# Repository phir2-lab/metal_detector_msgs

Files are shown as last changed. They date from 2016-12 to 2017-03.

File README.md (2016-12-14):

# Open Hardware, ROS-enable metal detector

This is a ROS package for the metal detector used in the [HRATC2017](http://inf.ufrgs.br/hratc2017/HRATC2017/Welcome.html) robot programming competition. The detector is based on open-hardware and software design.

## Usage

Program your Arduino with the firmware located in the "electronics/arduino_firmware" folder, connect it to your computer and run the launch file "detector.launch" with:

```
roslaunch metal_detector_msgs detector.launch
```

Or run the "arduino_node.py" node with:

```
rosrun metal_detector_msgs arduino_node.py [args]
```

The arguments (optional) to be passed to the node are:
* -b, --baud : Serial BAUD rate of the Arduino (default is 9600)
* --vid 	 : Vendor ID of the Arduino (default is 2341 for Arduino UNO)

This can also be seen when passing "-h" as argument for the node.

## Dependencies
* [ROS Indigo](http://wiki.ros.org/indigo)
* [pySerial](http://pyserial.readthedocs.io/en/latest/pyserial.html)

## Installation

Clone this package to your [Catkin Workspace](http://wiki.ros.org/catkin/Tutorials/create_a_workspace) "src" folder and [build your catkin packages](http://wiki.ros.org/catkin/Tutorials/using_a_workspace).

## Topic

The node receives frequency measurements from an Arduino via Serial Communication and publishes a topic of the Coil message type, of which the definition can be seen in the "msg" folder. Please see the readme of the "msg" folder for more information regarding interface with the coils.

## Parameters

The package uses ROS' parameter server to get and set its calibration parameters. They are defined as:

* calibration/sat : Saturation value for the coils in Hz
* calibration/ref : The desired reference value (when coils saturate)

By default, these parameters are set to "1.0".
The node also caps the readings to the reference value. In other words, it returns readings in the range of [0 - ref].

The parameters can be set statically via the "detector.launch" file. Just change the <param> tags accordingly, as seen in the example below:

```
<param name="calibration/sat" type="double" value="1853" /> 
```

Alternatively, to set the parameters dynamically, use the command below after launching the detector node:

```
rosparam set calibration/sat 1853
```

To check the value of a parameter, use the "rosparam get" command:
```
rosparam get calibration/sat
```

## Package organization

- model: has the Solidworks and Gazebo models for the metal detector;
- eletronics: it has the hardware design, eletronics, and Arduino programming;
- other dirs: ROS-related files such as launch, node, msg, etc.

## Troubleshooting

* Can't connect to my Arduino

The "arduino_node.py" sweeps your /dev/ folder for all available serial connections and finds the Arduino automatically via its Vendor ID (vid). The Arduino's vid can be set through the "--vid" argument when running the node, or by changing the "args" parameter in the launch file. To find out what your Arduino vid is, connect it to a computer and run the "lsusb" command in a terminal. The vid will be there, like this:

<pre>
Bus 002 Device 006: ID 0cf3:e005 Atheros Communications, Inc. 
Bus 002 Device 003: ID 0c45:6712 Microdia 
Bus 002 Device 009: ID <b>2341</b>:0043 Arduino SA Uno R3 (CDC ACM)
                          ^
                       [This is your VID]   
</pre>

## Credits

- The original eletronics board was designed by [LucasLab](https://translate.google.com/translate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)
- The integration of the eletronics board with Arduino is by Augusto Bergamin;
- The Arduino firmware is by Augusto Bergamin and Renan Maidana;
- The ROS node design and ROS launch is by Renan Maidana;
- Conversion from SolidWorks to Gazebo by Renan Maffei and Mathias Mantelli.
- Readmes edits by Alexandre Amory.

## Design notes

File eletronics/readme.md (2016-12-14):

# Electronics

This directory you will find:

- Arduino Firmware
- original metal detector PCB design [LucasLab](https://translate.google.com/translate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)
- modified metal detector PCB design by Augusto Bergamin
  - integrated with Arduino UNO
  - including support to two coils

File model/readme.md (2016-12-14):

# Metal Detector Support

This model, drawn in SolidWorks and exported to Gazebo, is the support/arm for the metal detector.

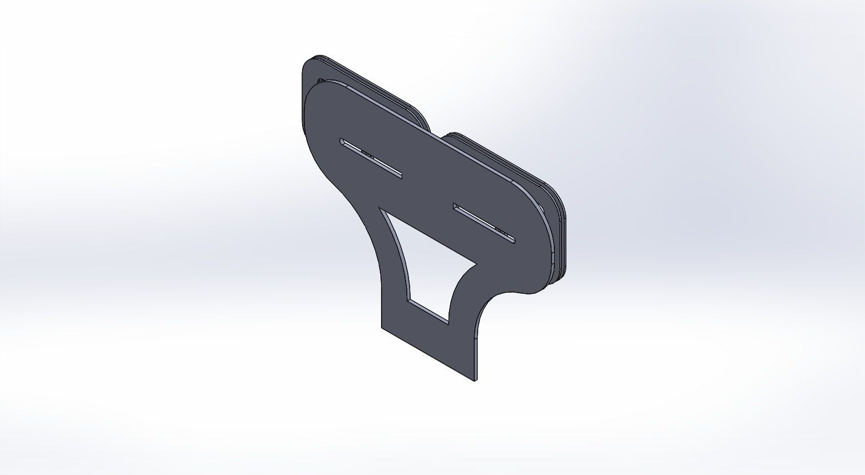
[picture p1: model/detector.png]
Metal detector arm


This image shows the position of the coils.

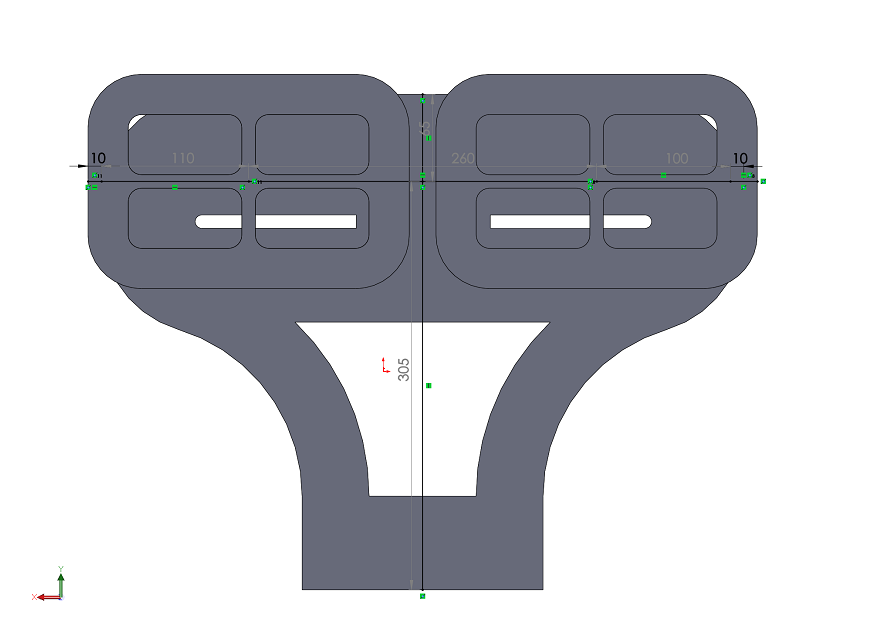
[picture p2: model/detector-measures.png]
Metal detector arm


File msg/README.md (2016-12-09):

### Note

In the topic published by the metal detector node, the coils' measurements are contained in the "left_coil" and "right_coil" for the left and right coils respectively, in the Coil message type (Coil.msg). The coils are measured one at a time, and switching between them occurs in a fixed interval.

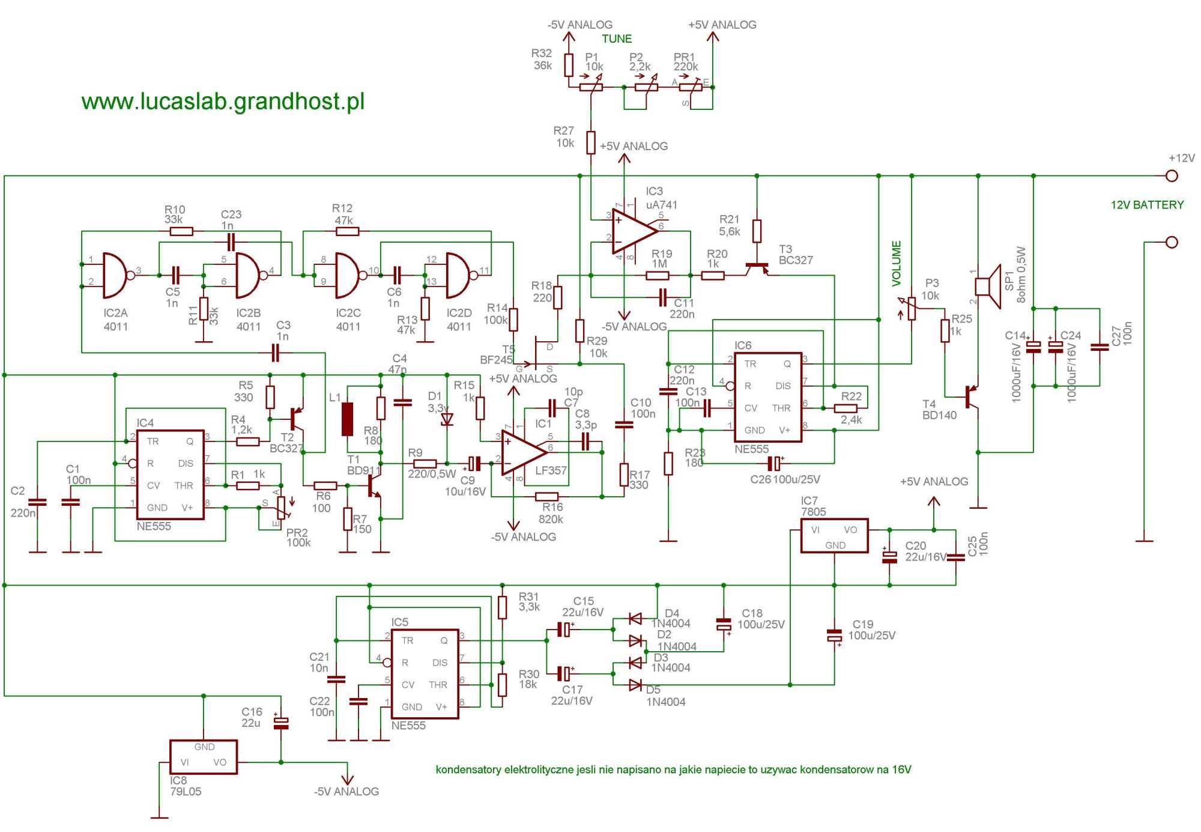
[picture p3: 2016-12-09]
eletronics/pcb/schematwykrywacza.JPG

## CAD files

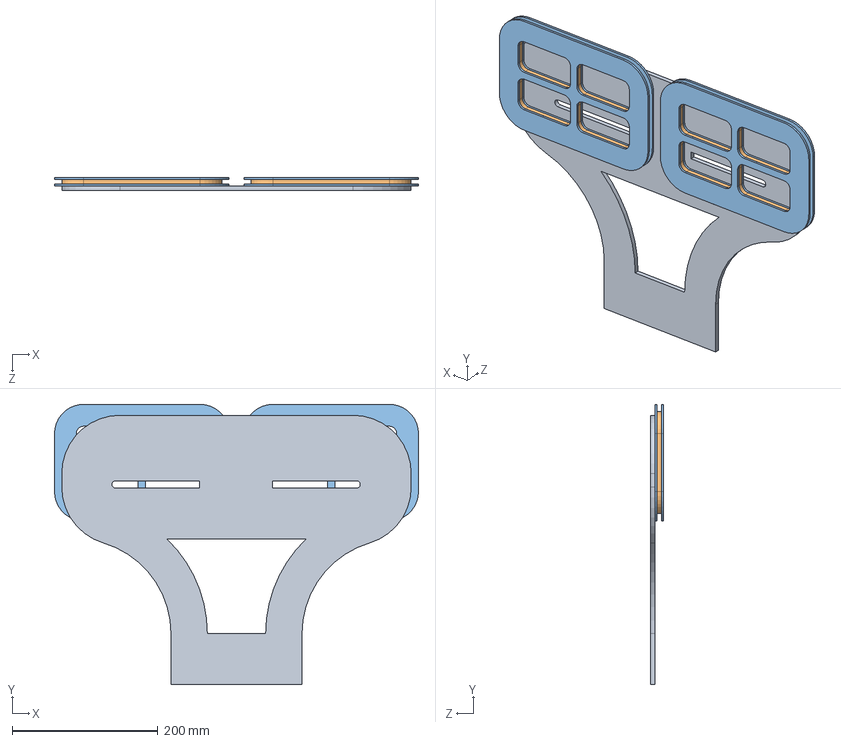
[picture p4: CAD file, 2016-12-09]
model/solidworks/Detector.SLDASM
500.0 x 385.0 x 18.0 mm
Suportev5
Bobina x 2
BobinaBorda x 4

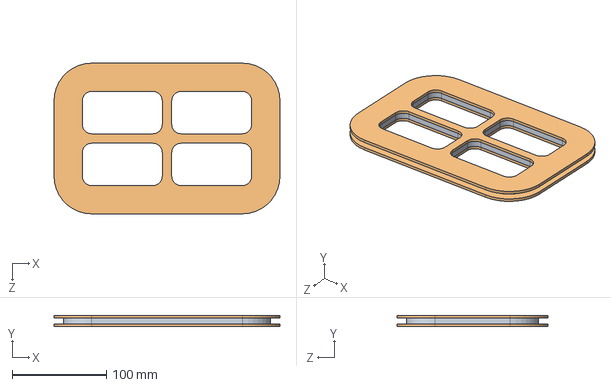
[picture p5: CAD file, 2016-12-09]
model/solidworks/MontagemBobina.SLDASM
240.0 x 12.0 x 160.0 mm
Bobina
BobinaBorda x 2

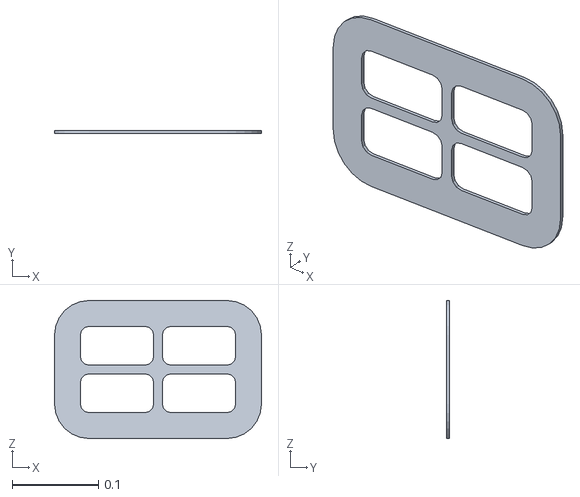
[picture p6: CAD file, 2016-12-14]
model/gazebo/meshes/left_coil.STL
0.24 x 0.003 x 0.16

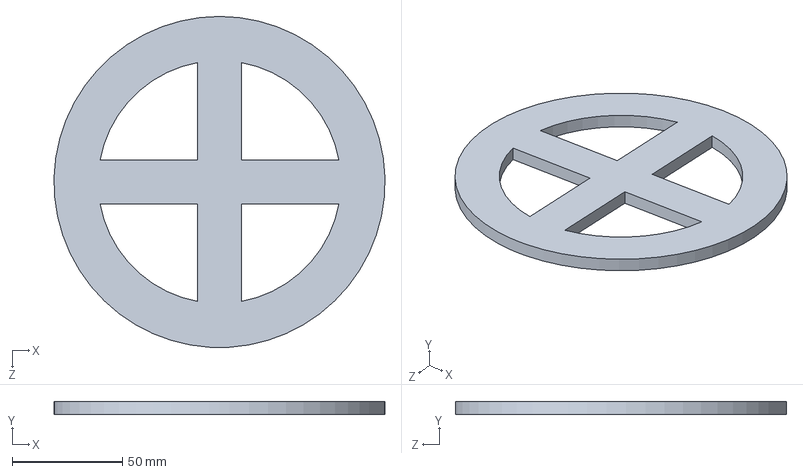
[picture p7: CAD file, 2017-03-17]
model/solidworks/Bobina lateral.SLDPRT
149.9 x 6.00 x 150.0 mm

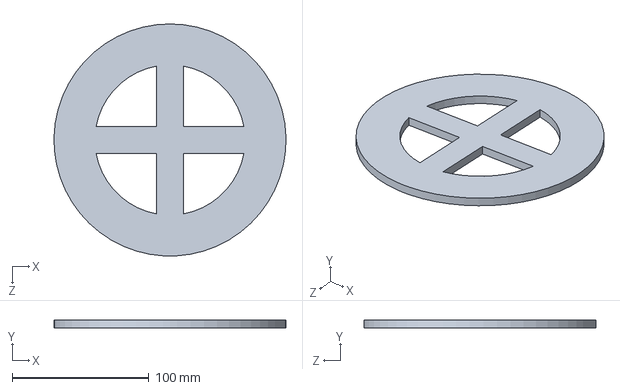
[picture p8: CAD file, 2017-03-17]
model/solidworks/Bobina TOP.SLDPRT
169.9 x 6.00 x 170.0 mm

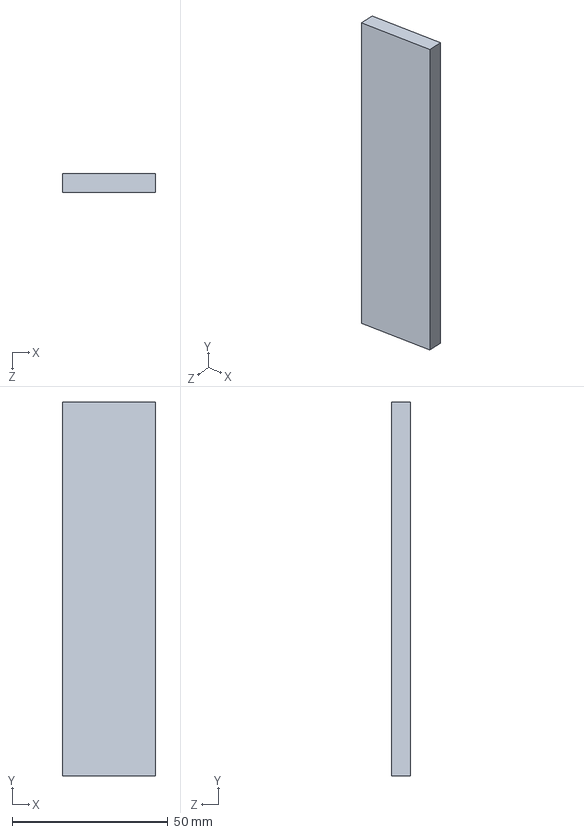
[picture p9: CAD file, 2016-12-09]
model/solidworks/Suporte-Dobradica.SLDPRT
30.0 x 120.0 x 6.00 mm

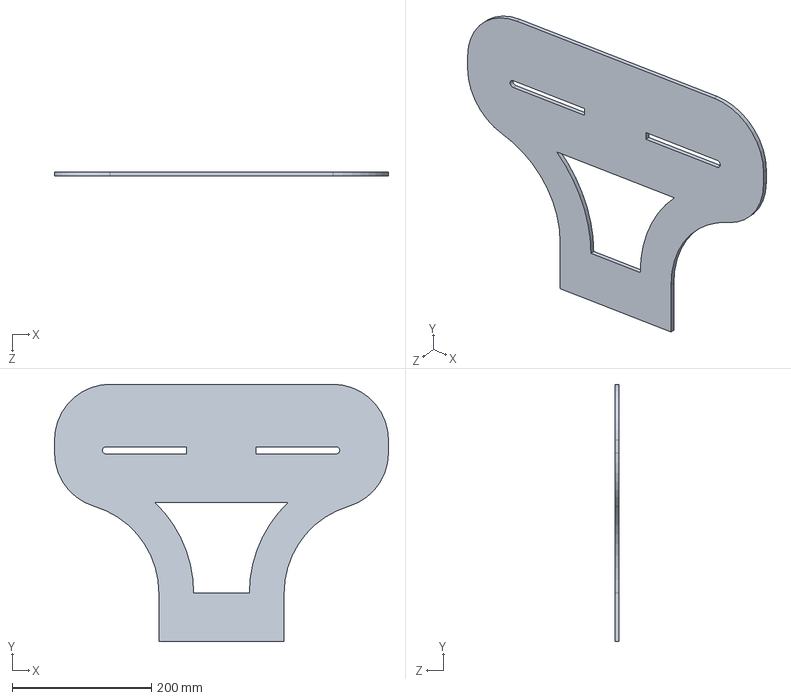
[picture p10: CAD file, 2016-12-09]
model/solidworks/Suportev5.SLDPRT
480.0 x 370.0 x 6.00 mm

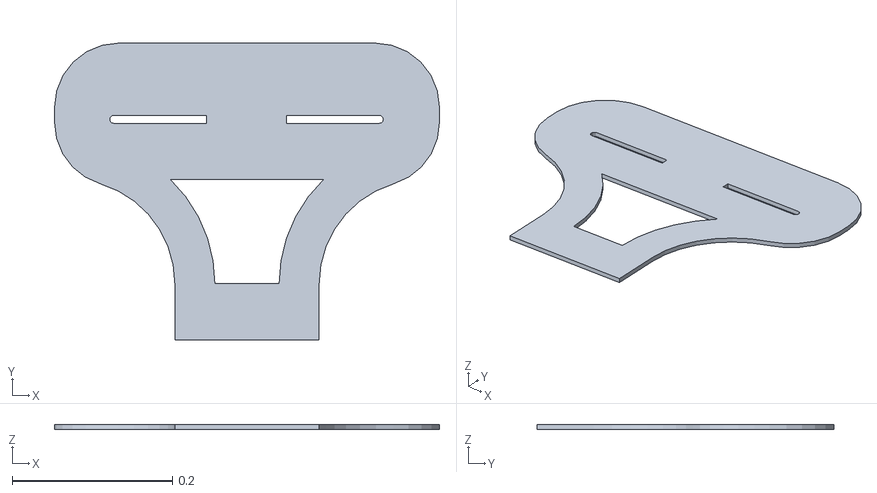
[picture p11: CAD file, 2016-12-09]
model/gazebo/meshes/metal_detector_support.STL
0.48 x 0.37 x 0.006

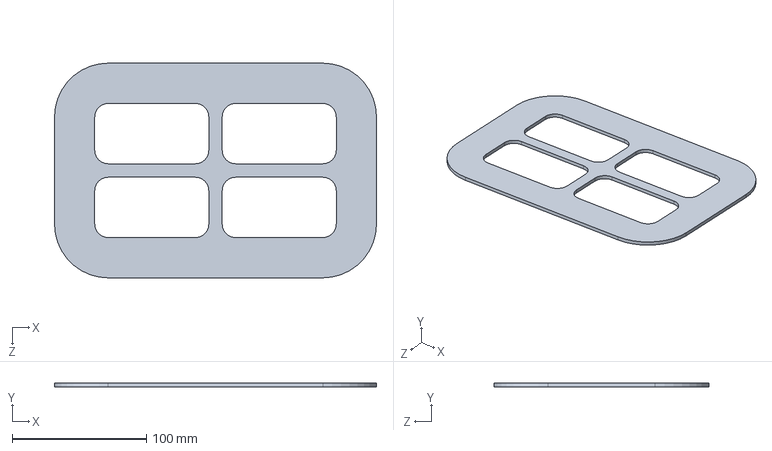
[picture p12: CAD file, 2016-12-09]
model/solidworks/BobinaBorda.SLDPRT
240.0 x 3.00 x 160.0 mm

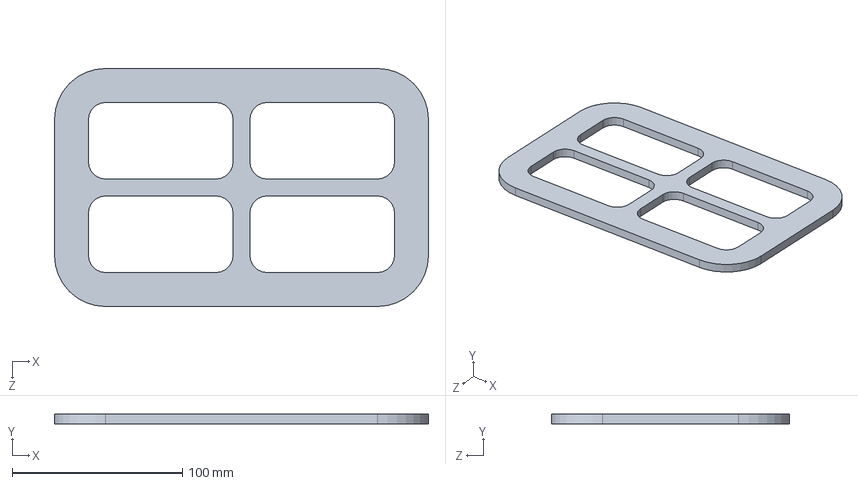
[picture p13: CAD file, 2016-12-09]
model/solidworks/Bobina.SLDPRT
220.0 x 6.00 x 140.0 mm

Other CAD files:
model/gazebo/meshes/right_coil_support.STL
model/gazebo/meshes/left_coil_support.STL
model/gazebo/meshes/right_coil.STL

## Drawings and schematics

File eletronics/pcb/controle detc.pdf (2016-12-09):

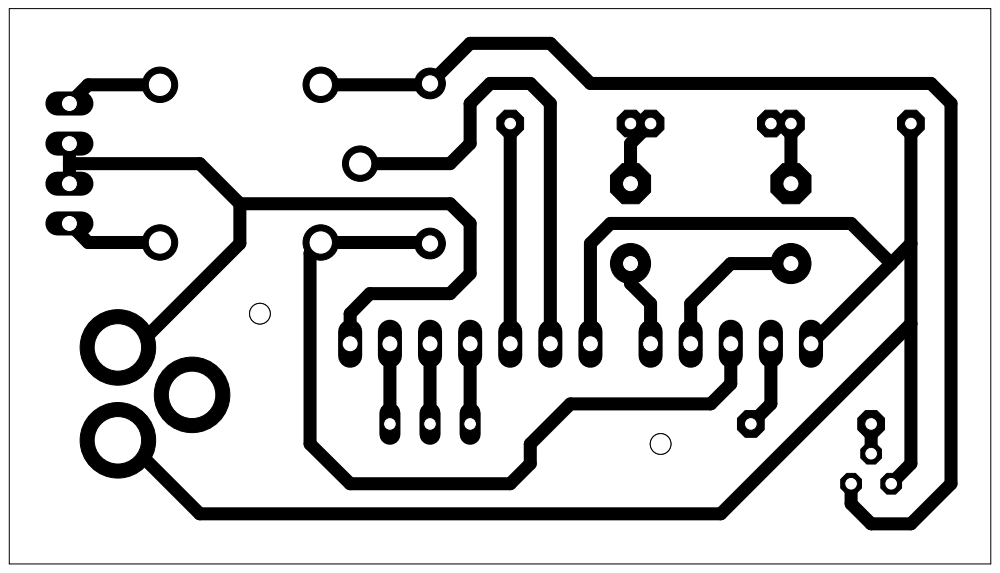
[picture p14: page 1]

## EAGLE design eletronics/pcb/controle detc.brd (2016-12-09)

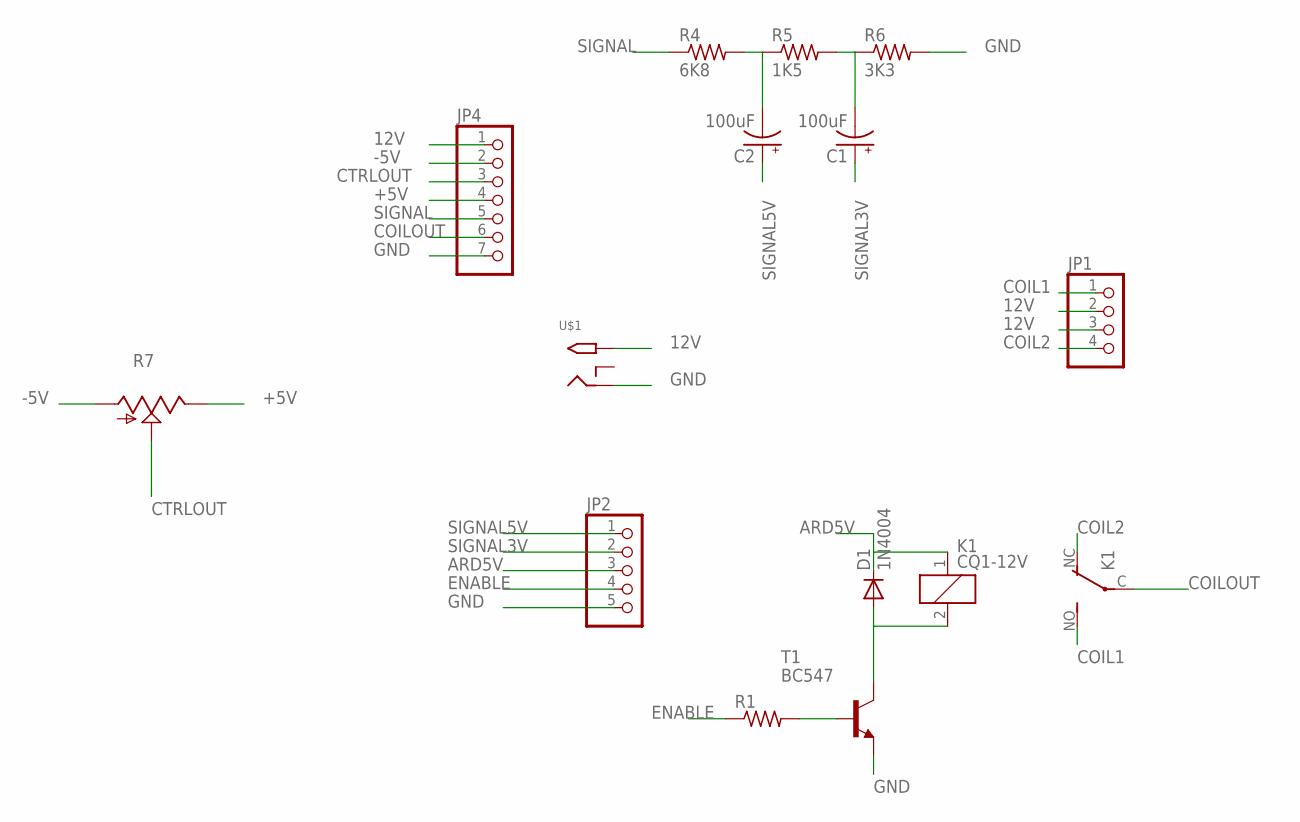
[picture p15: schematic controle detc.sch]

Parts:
C1, C2: 100uF; E5-8,5
D1: 1N4004; DO41-10
JP1: PINHD-1X4; 1X04
JP2: PINHD-1X5; 1X05
JP4: PINHD-1X7; 1X07
K1: CQ1-12V; CQ1
R1: R-US_0207/7; 0207/7
R4: 6K8; 0207/7
R5: 1K5; 0207/7
R6: 3K3; 0207/7
R7: TRIM_US-S64W; S64W
T1: BC547; TO92
U$1: 2.1MMJACKTHM; PJ-102A

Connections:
12V: JP1.2, JP1.3, JP4.1, U$1.TIP
+5V: JP4.4, R7.E
-5V: JP4.2, R7.A
ARD5V: D1.C, JP2.3, K1.1
COIL1: JP1.1, K1.NO (S)
COIL2: JP1.4, K1.NC (O)
COILOUT: JP4.6, K1.C
CTRLOUT: JP4.3, R7.S
ENABLE: JP2.4, R1.1
GND: JP2.5, JP4.7, R6.2, T1.1 (E), U$1.RING
unnamed: R1.2, T1.2 (B)
unnamed: D1.A, K1.2, T1.3 (C)
unnamed: C2.-, R4.2, R5.1
unnamed: C1.-, R5.2, R6.1
SIGNAL: JP4.5, R4.1
SIGNAL3V: C1.+, JP2.2
SIGNAL5V: C2.+, JP2.1

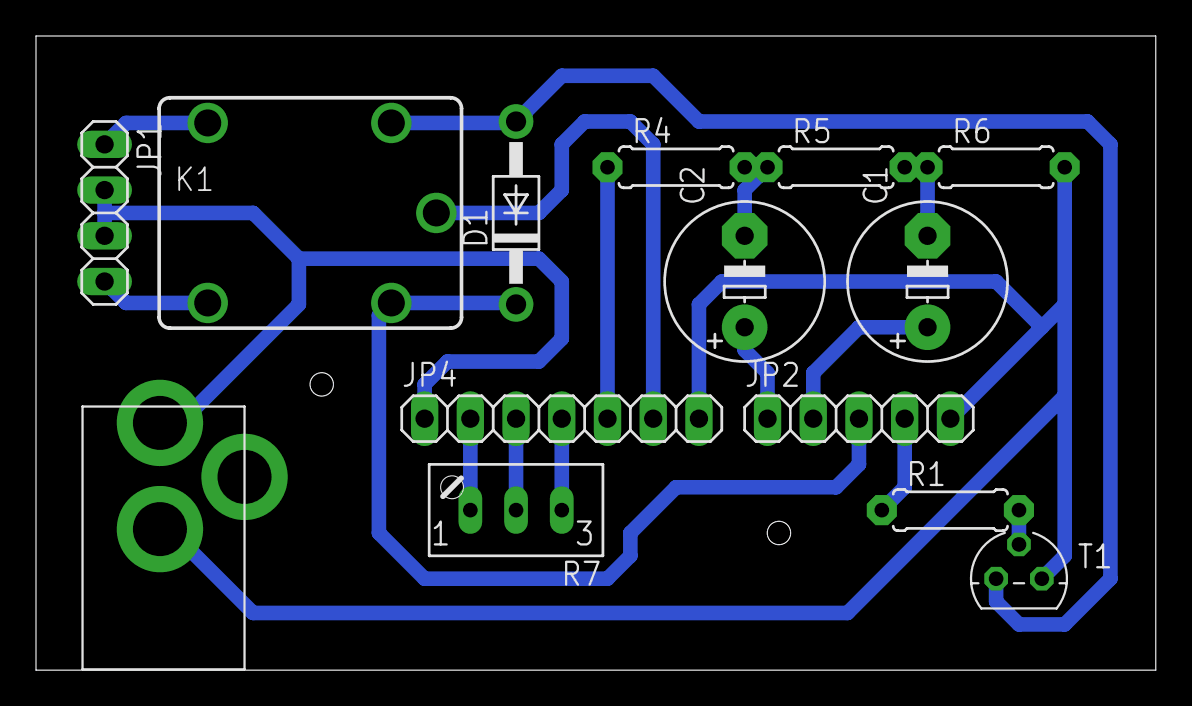
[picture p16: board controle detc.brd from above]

Board: 2 copper layers, 62.2 x 35.2 mm, 14 parts (0 on the bottom side), 17 nets.

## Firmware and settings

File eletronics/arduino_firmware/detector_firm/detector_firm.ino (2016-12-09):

#include <avr/io.h>
#include <avr/interrupt.h>

volatile double temp;
volatile int freqL = 0;
volatile int freqR = 0;
long int swit = 0;
bool Rstate = 0;

//Interrupt vector for INT0 (pin D2)
ISR (INT0_vect)
{
  if(swit >= 400)
  {
  	//Bobina direita
    if(Rstate == true){
      freqR = (1/((micros() - temp)/1000000));
  	}
  	//Bobina esquerda
    else{
      freqL = (1/((micros() - temp)/1000000));
  	}
  }
  temp = micros();
}

void setup()
{
  pinMode(13,OUTPUT);	//Relay pin (D13)
  temp = micros();

  Serial.begin(9600);
  
  cli(); //Disable interrupts for setup

  //Interrupt (on Arduino Uno pin 2)
  DDRD &= ~(1 << DDD2);     // Clear the PD2 pin
  PORTD |= (1 << PORTD2);    // turn On the Pull-up
  EICRA |= (1 << ISC01);    // set INT0 to trigger on falling edge
  EIMSK |= (1 << INT0);     // Turns on INT0
  
  sei();	//Re-enable interruptsd
}

void loop()
{
  //After some time, switch coils
  if(swit >= 800)
  { 
    Rstate = not(Rstate); 
    swit = 0;
    digitalWrite(13,Rstate);
    freqL = 0;
    freqR = 0;
  }
  
  Serial.print(freqL);
  Serial.print(",");
  Serial.print(freqR);
  Serial.print("\n");

  swit++;
}

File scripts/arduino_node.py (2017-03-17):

#!/usr/bin/env python

import os
import sys
import time
import rospy
import signal
import serial
import argparse
import serial.tools.list_ports
from serial import SerialException
from metal_detector_msgs.msg import Coil

# ROS Parameters
pub_freq = 10
pub_topic = 'metal_detector'
ser = serial.Serial()

# Coil message
coil_msg = Coil()
coil_msg.header.frame_id = 'Coils'
coil_msg.header.seq = 0

# Argument parser
parser = argparse.ArgumentParser()

# Regular arguments
parser.add_argument("-b", "--baud",
                    default=9600,
                    help='defines baud rate of serial port')
parser.add_argument("--vid",
                    default='2341',
                    help='vendor ID of Arduino device (default is 2341 for Arduino UNO)')

# Parse known arguments because ROSLAUNCH passes unknown arguments to node
args, unknown = parser.parse_known_args()

def handle_ctrl_c(signal, frame):
	ser.close()
	sys.exit(130)

def find_arduino(vid='2341'):
	'''
	Sweeps all available serial ports and finds the arduino port via its 
	Vendor ID.

	Arguments:
		vid - Vendor ID for the Arduino (2341 is the default for UNO)

	Returns:
		port - String with the arduino port
	'''

	# Make a list of all available ports on the system
	available_ports = list(serial.tools.list_ports.comports())
	
	# Sweep all ports
	for port in available_ports:
		for string in port:			# Sweep all strings in a given port list
			if vid in string:		# If any of these strings contain the VID
				return port[0]		# Return the first string, which is the port name

	return None

def connect(timeout=10):
	'''
	Attempts to connect to a serial port specified by "ser.port".

	Arguments:
		timeout - Time to display message "Could not find Arduino"
	'''
	t1 = time.time()
	while ser.port == None:
		t2 = time.time()
		ser.port = find_arduino(args.vid)
		ser.baudrate = args.baud
		if (t2 - t1) > timeout:
			rospy.loginfo("Could not find Arduino. Retrying...")
			t1 = t2
	
	try:	
		ser.open()
		rospy.loginfo("Connected to device at %s", ser.port)
	except:
		pass

def detector():
	'''
	Gets values from serial and publishes them as Coil.msg in the detector topic
	'''
	pub = rospy.Publisher('metal_detector', Coil, queue_size=10)
	rospy.init_node(pub_topic, anonymous=True)
	rate = rospy.Rate(pub_freq) # 10hz

	rospy.loginfo("Connecting...")
	while not ser.isOpen():
		connect(10)

	rospy.loginfo("Publishing at topic \'%s\' at a rate of %d hz", pub_topic, pub_freq)
	buf_str = ''
	last_received = ''
	# Do this until node is shutdown
	while not rospy.is_shutdown():
		# Get current time for coil message
		coil_msg.header.stamp = rospy.Time.from_sec(time.time())

		# Get calibration parameters from parameter server
		try:
			sat = float(rospy.get_param('/metal_detector/calibration/sat'))
		except KeyError:	# rospy will raise this error if the parameter is not found
			sat = 1.0		# default to 1.0
		try:
			ref = float(rospy.get_param('/metal_detector/calibration/ref'))
		except KeyError: 	# rospy will raise this error if the parameter is not found
			ref = 1.0		# default to 1.0

		# Parse the buffer string and get the last available data (in pairs)
		try:
			buf_str += ser.read(ser.inWaiting())
		except IOError:
			rospy.loginfo("Lost connection to Arduino! Trying to reestablish connection...")
			ser.close()
			ser.port = None
			while not ser.isOpen():
				connect(5)
			rospy.loginfo("Publishing at topic \'%s\' at a rate of %d hz", pub_topic, pub_freq)
				
		if '\n' in buf_str:
			lines = buf_str.split('\n')
			last_received = lines[-2]
			buf_str = lines[-1]

		data = last_received.split(',')

		# Catch some silly errors (when serial sends two ","s for example)
		try:
			# Normalize the data comming from the coils, and caps them to the interval [0 - ref]
			coil_msg.left_coil = max(0, min(ref*float(data[0])/sat, ref))
			coil_msg.right_coil = max(0, min(ref*float(data[1])/sat, ref))
		except (ValueError, IndexError):
			pass
		pub.publish(coil_msg)
		rate.sleep()
	ser.close()

if __name__ == '__main__':
	signal.signal(signal.SIGINT, handle_ctrl_c)
	try:
		detector()
	except rospy.ROSInterruptException:
		pass

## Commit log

2016-11-08 Upload metaldetector solidworks files
    SW 2014
    [Bobina TOP.SLDPRT, Bobina lateral.SLDPRT, Detector.SLDASM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]
2016-11-08 Added metal detector arduino firmware
2016-11-09 Adicionado Esquemáticos do detector
    [Wykrywacz metali PI.brd, controle detc.brd, controle detc.sch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]
2016-11-09 Added Gazebo model of the metal detector
    [left_coil.STL, left_coil_support.STL, metal_detector_support.STL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]
2016-11-10 Update of metal_detector URDF model
    [metal_detector.urdf.xacro, metal_detector_support.URDF]
2016-11-18 Corrected syntax bug in detector_firm.ino
    [detector_firm.ino]
2016-11-19 Added scripts folder with arduino_node.py file
2016-11-19 Changed arduino_node.py
2016-11-28 Adicionadas Bobinas Novas
    [Bobina TOP.SLDPRT, Bobina lateral.SLDPRT, Bobina.SLDPRT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]
2016-12-05 Modified arduino_node.py
2016-12-05 hanged arduino_node.py
2016-12-07 Changed arduino_node.py to reflect changes in Coil.msg file
2016-12-07 Corrected typos in comments on arduino_node.py
    [arduino_node.py]
2016-12-09 URDF of the metal detector updated
    [left_coil.STL, left_coil_support.STL, metal_detector.urdf.xacro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]
2017-03-11 added bag files and changed arduino firmware
    [Bobina TOP.SLDPRT, Bobina lateral.SLDPRT]
2017-03-16 remove duplicated arduino firmware
